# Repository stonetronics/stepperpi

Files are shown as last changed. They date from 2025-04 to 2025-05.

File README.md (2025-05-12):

# stepperpi
control of one stepper motor (NEMA17) and measurement by rotary encoder with a raspberry pi through a ethernet interface  

## pcb
The pcb folder contains a PCB that fits on to a regular raspberry pi (drawn in KiCAD 9.0). It holds two A4988 stepper motor drivers complete with JST connector for a NEMA17 motor and two JST connectors for endswitches, all following common pin layouts as they are used with 3D printers. Options for microstepping are set through a solder jumper.  
Each hardware pin connection of both the stepper driver and endswitches is connected to the raspberry pi through a solder jumper and can be enabled/disabled as needed.  
An additional DC/DC converter is present on the board. It steps down the input voltage to the 5V needed by the raspberry pi, eliminating the need for a seperate USB power supply. The connection to the DC/DC converter is optional and can be enabled through a jumper.  

## code
In the code directory, three subdirectories exist. One holds a jupyter notebook for the analysis and development of the stepping algorithm and the other one holds a c++ project for the control of the stepper motor on the raspberry pi through a socket interface. Another directory holds a client written in python which connects to the raspberry pi's socket and enables the user to send and receive string commands and messages. Please refer to the respective readme for further info.

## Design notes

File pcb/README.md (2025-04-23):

# PCB external content

This pcb uses/adapts external library content:

## A4988 step motor driver
3D model:  
https://grabcad.com/library/driver-a4988-1

## Raspberry Pi
3D model:  
https://grabcad.com/library/raspberry-pi-4-model-b-1
Footprint:
https://github.com/devbisme/RPi_Hat_Template

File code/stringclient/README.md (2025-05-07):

# stringclient

To use this client script run it via command line with `python client.py PLACE.RASPBERRYPI.IP.HERE`. Optionally, you can also set the host raspberry pi IP inside the python script and run it without arguments.  
At the start of the script, it will connect to the host.  

In order to send a string to the host, simply enter your string and press enter. If there is any response from the host, it will be displayed in the output of the script.  

Exit the script by entering the message `bye`.

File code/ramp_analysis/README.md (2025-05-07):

# ramp analysis

When a stepper motor is driven at constant speed directly from standstill, it faces very high torques and inertia which may lead to the loss of steps.  
In order to circumvent step loss when driving the stepper motor, an algorithm is employed which ramps up the speed with constant acceleration, holds the maximum speed and ramps down the speed again before reaching the desired number of steps. An exemplary resulting velocity profile is shown in the graph:  
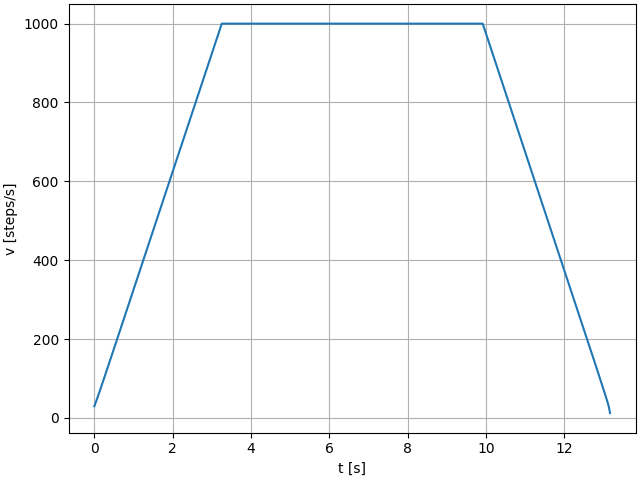
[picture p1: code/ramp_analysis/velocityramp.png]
velocityramp
  
  
The calculations in the python notebook serve as the basis for the development of the c++ code which runs on the raspberry pi and controls the stepper motor driver. In essence, the time between each step is the crucial quantity that is required to follow the velocity profile.

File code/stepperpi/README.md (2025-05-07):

# stepperpi c++ code  
This directory holds all of the c++ code that handles driving the stepper motor and exposing an interface on TCP which allows remote control of the system

## functional description  
TBW  

## requirements & install  
TBW  

## remote interface  
TBCD&TBW

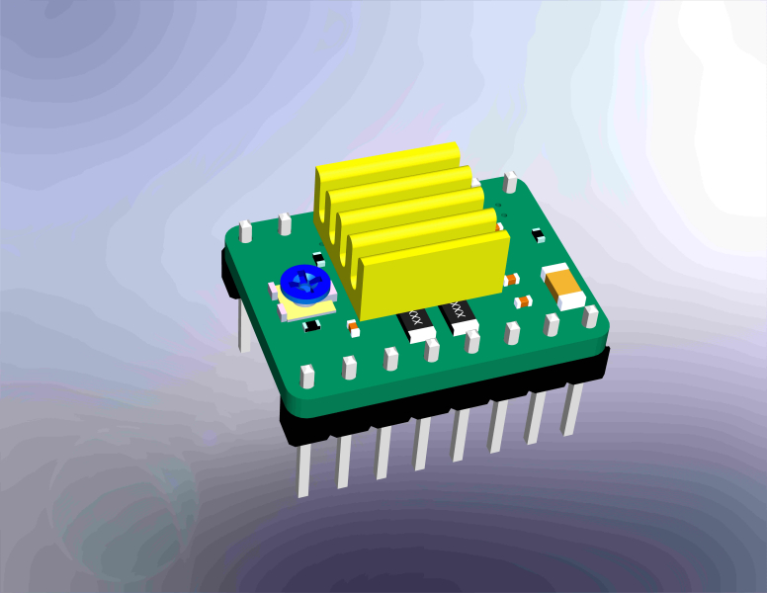
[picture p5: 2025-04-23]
pcb/stepperpi/3D/A4988/stepstick_1.jpg

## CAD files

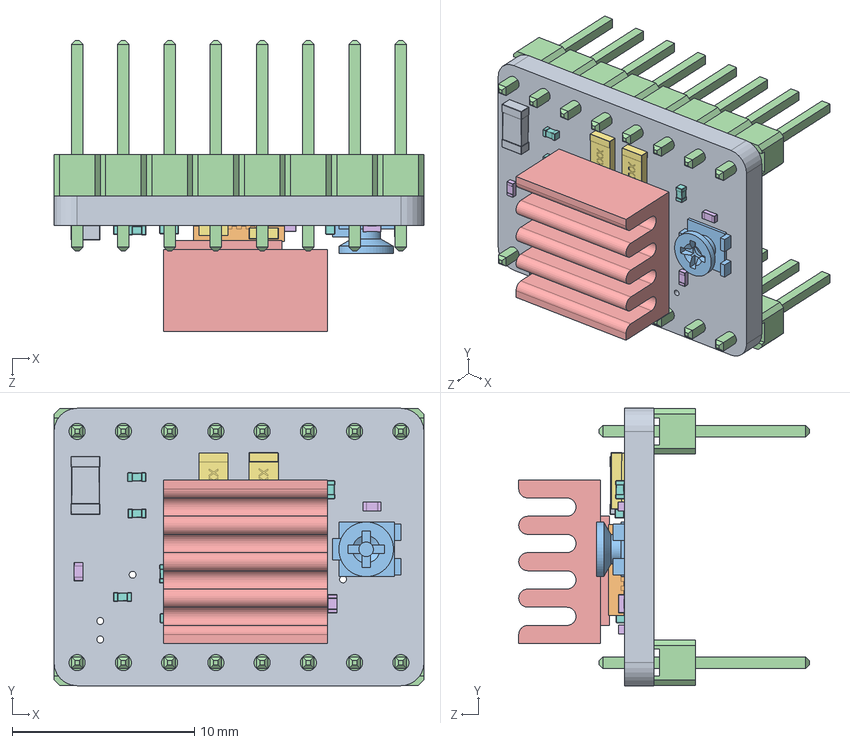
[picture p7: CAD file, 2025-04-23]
pcb/stepperpi/3D/A4988/stepstick.SLDASM
20.3 x 15.2 x 16.0 mm
stepstick
QFN28ET_A4983
TRIMPOT3MM_TRIMPOTSMD
Pin header pitch 2.54mm_08 contacts x 2
Heatsink For A4988
R0402-01 x 4
R1206-01 x 2
C0402 x 6
C1206B

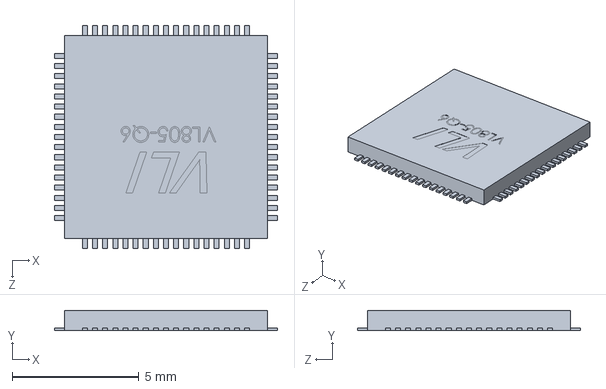
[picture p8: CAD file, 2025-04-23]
pcb/stepperpi/3D/raspberry/VIA VL805 PCIe USB 3.0 controller, RPi4ModelB.SLDPRT
8.80 x 0.8 x 8.80 mm

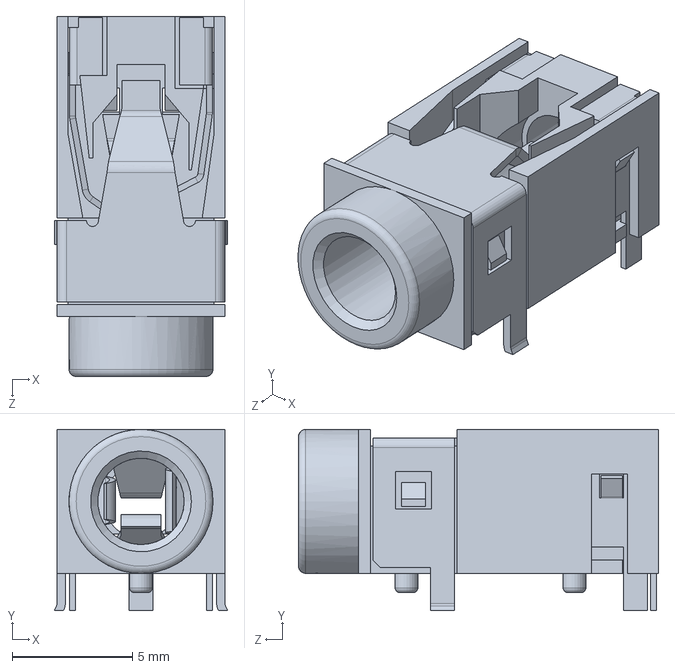
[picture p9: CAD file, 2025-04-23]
pcb/stepperpi/3D/raspberry/Microphone Plug, RPi4ModelB.SLDPRT
7.23 x 7.55 x 15.0 mm

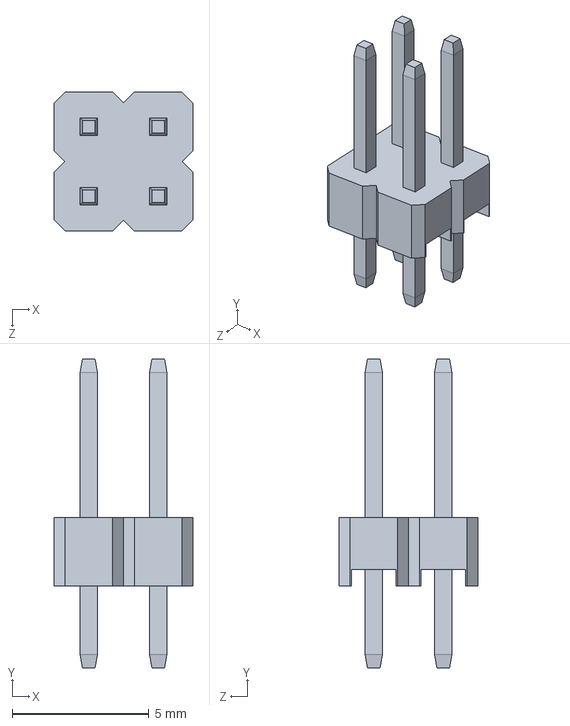
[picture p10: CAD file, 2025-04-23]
pcb/stepperpi/3D/raspberry/2.54 mm DUPONT MALE PIN HEADER, POE, 2X2, RPi4ModelB.SLDPRT
5.08 x 11.3 x 5.08 mm

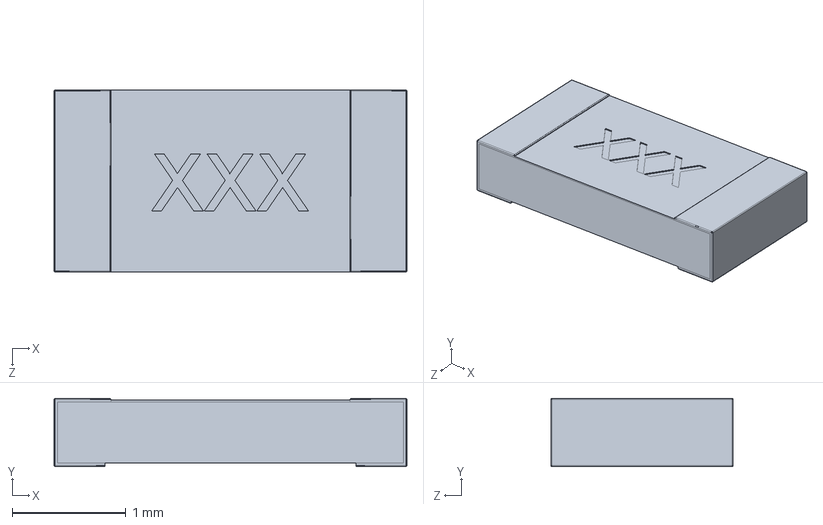
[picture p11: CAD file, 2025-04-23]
pcb/stepperpi/3D/A4988/R1206-01.SLDPRT
3.10 x 0.6 x 1.60 mm

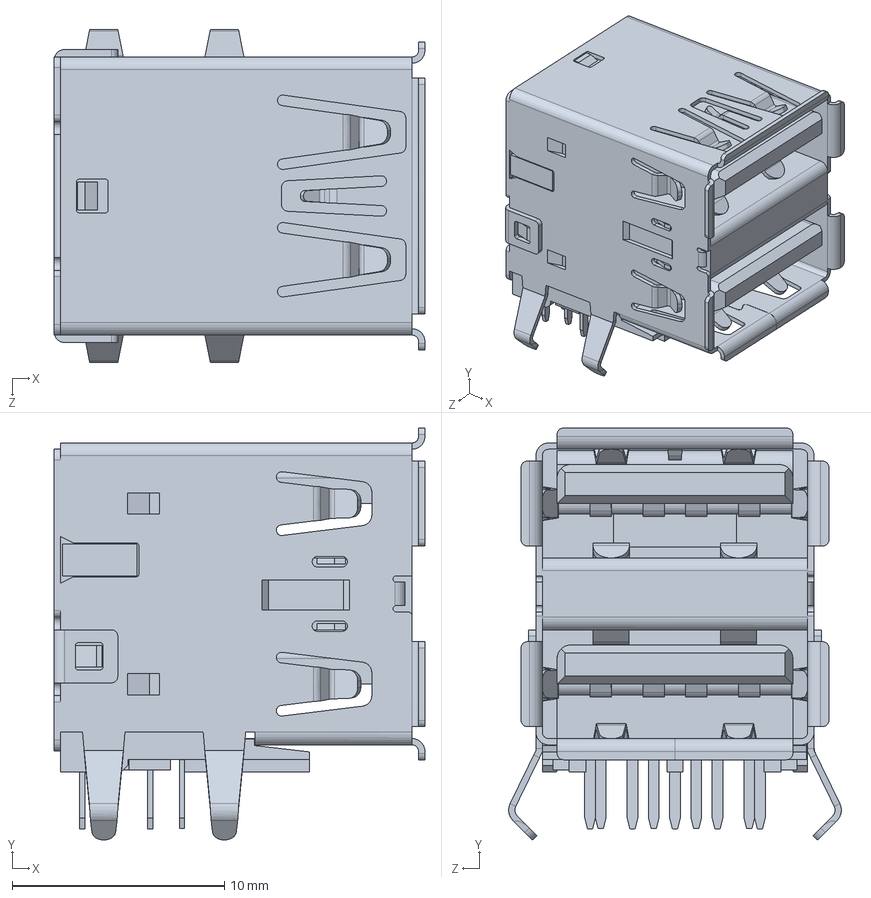
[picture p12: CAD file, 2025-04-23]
pcb/stepperpi/3D/raspberry/2X USB3.0 PORTS, RPi4ModelB.SLDPRT
17.5 x 19.4 x 15.7 mm

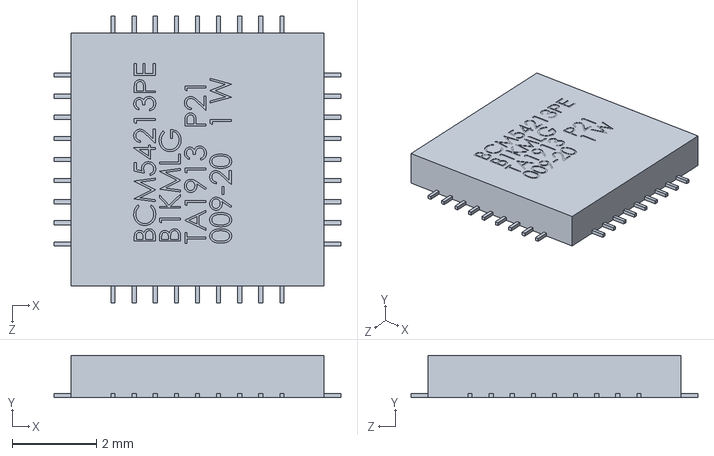
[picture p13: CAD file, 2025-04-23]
pcb/stepperpi/3D/raspberry/Broadcom BCM54213PE Gigabit Ethernet Transceiver, RPi4ModelB.SLDPRT
6.80 x 1.00 x 6.80 mm

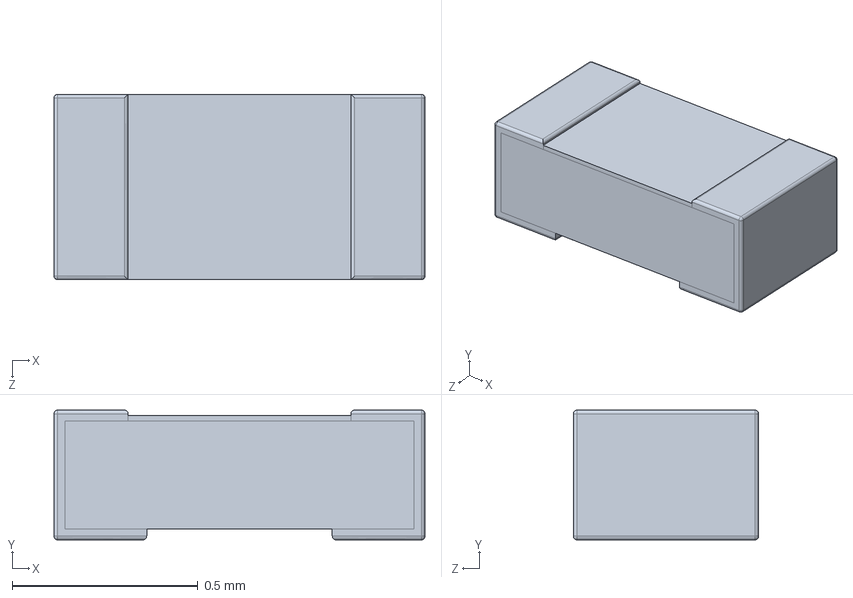
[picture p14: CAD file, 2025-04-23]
pcb/stepperpi/3D/A4988/R0402-01.SLDPRT
1.00 x 0.35 x 0.5 mm

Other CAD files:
pcb/stepperpi/3D/A4988/TRIMPOT3MM_TRIMPOTSMD.sldprt
pcb/stepperpi/3D/A4988/Pin header pitch 2.54mm_08 contacts.sldprt
pcb/stepperpi/3D/A4988/A4988-1.STEP
pcb/stepperpi/3D/A4988/0402RES_RESISTOR0402RES.sldprt
pcb/stepperpi/3D/A4988/Heatsink For A4988.sldprt
pcb/stepperpi/3D/A4988/QFN28ET_A4983.sldprt
pcb/stepperpi/3D/A4988/0805_RESISTOR.sldprt
pcb/stepperpi/3D/A4988/0402CAP_CAP0402CAP.sldprt
pcb/stepperpi/3D/A4988/1206_CAP1206.sldprt
pcb/stepperpi/3D/A4988/A4988-1.SLDASM
pcb/stepperpi/3D/A4988/C0402.SLDPRT
pcb/stepperpi/3D/A4988/C1206B.SLDPRT
pcb/stepperpi/3D/A4988/stepstick.sldprt
pcb/stepperpi/3D/raspberry/2.54 mm DUPONT MALE PIN HEADER, IO, 2X40, RPi4ModelB.SLDPRT
pcb/stepperpi/3D/raspberry/2X USB2.0 PORTS, RPi4ModelB.SLDPRT
pcb/stepperpi/3D/raspberry/Broadcom BCM2711B0 CPU, RPi4ModelB.SLDPRT
pcb/stepperpi/3D/raspberry/Cypress CYW43455 Wireless Module Cover, RPi4ModelB.SLDPRT
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

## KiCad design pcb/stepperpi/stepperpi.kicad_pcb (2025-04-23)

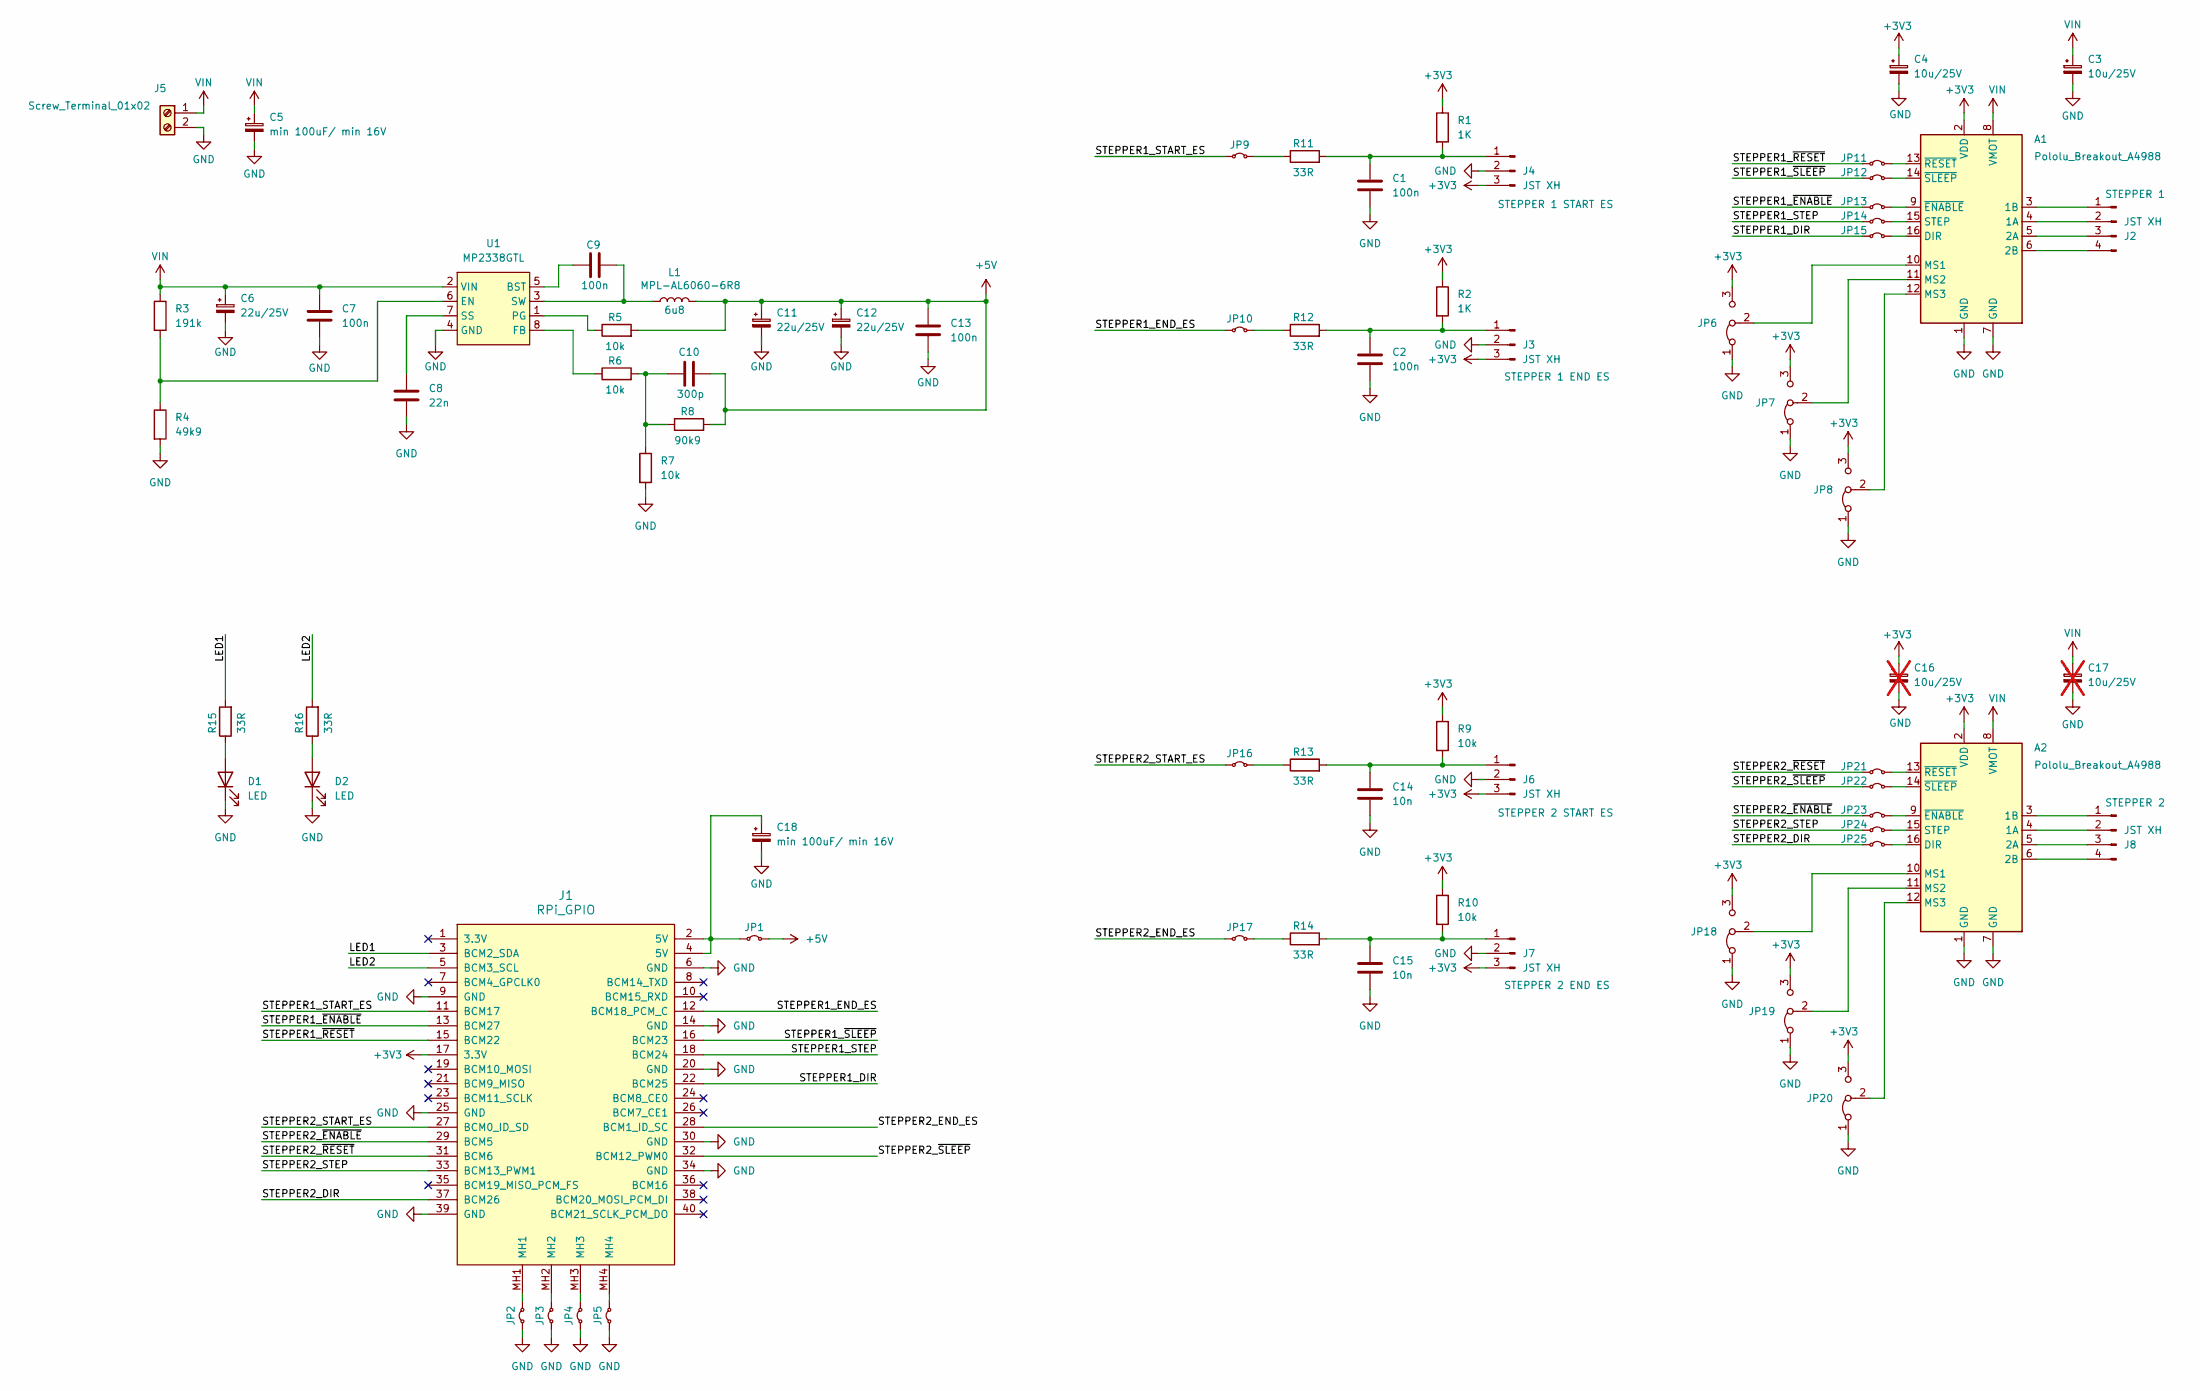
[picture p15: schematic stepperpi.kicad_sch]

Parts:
A1, A2: Pololu_Breakout_A4988; Pololu_Breakout-16_15.2x20.3mm
C1, C2, C7, C9, C13: 100n; C_0805_2012Metric
C3, C4: 10u/25V; CP_EIA-6032-28_Kemet-C_Pad2.25x2.35mm_HandSolder
C5, C18: min 100uF/ min 16V; CP_EIA-7343-31_Kemet-D_Pad2.25x2.55mm_HandSolder
C6, C11, C12: 22u/25V; CP_EIA-7132-28_AVX-C_Pad2.72x3.50mm_HandSolder
C8: 22n; C_0805_2012Metric
C10: 300p; C_0805_2012Metric
C14, C15: 10n; C_0805_2012Metric
C16, C17: 10u/25V; CP_EIA-6032-28_Kemet-C_Pad2.25x2.35mm_HandSolder; not fitted
D1, D2: LED; LED_0805_2012Metric_Pad1.15x1.40mm_HandSolder
J1: RPi_GPIO; RPI_Hat_B+ no display slot
J2, J8: JST XH; JST_XH_B4B-XH-A_1x04_P2.50mm_Vertical
J3, J4, J6, J7: JST XH; JST_XH_B3B-XH-A_1x03_P2.50mm_Vertical
J5: Screw_Terminal_01x02; TerminalBlock_bornier-2_P5.08mm
JP1, JP2, JP3, JP4, JP5, JP9, JP10, JP11, JP12, JP13, JP14, JP15, JP16, JP17, JP21, JP22, JP23, JP24, JP25: Jumper_2_Small_Bridged; SolderJumper-2_P1.3mm_Open_TrianglePad1.0x1.5mm
JP6, JP7, JP8, JP18, JP19, JP20: Jumper_3_Bridged12; SolderJumper-3_P2.0mm_Open_TrianglePad1.0x1.5mm_NumberLabels
L1: 6u8; L_MPL-AL6060-6R8; Part MPL-AL6060-6R8
R1, R2: 1K; R_0805_2012Metric
R3: 191k; R_0805_2012Metric
R4: 49k9; R_0805_2012Metric
R5, R6, R7, R9, R10: 10k; R_0805_2012Metric
R8: 90k9; R_0805_2012Metric
R11, R12, R13, R14, R15, R16: 33R; R_0805_2012Metric
U1: MP2338GTL; SOT-583-8

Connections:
+3V3: A1.2 (VDD), A2.2 (VDD), C4.1, C16.1, J1.17 (3.3V), J3.3, J4.3, J6.3, J7.3, JP6.3 (B), JP7.3 (B), JP8.3 (B), JP18.3 (B), JP19.3 (B), JP20.3 (B), R1.1, R2.1, R9.1, R10.1
+5V: C10.2, C11.1, C12.1, C13.1, JP1.1 (A), L1.2, R5.2, R8.2
/LED1: J1.3 (BCM2_SDA), R15.2
/LED2: J1.5 (BCM3_SCL), R16.2
/STEPPER1_DIR: J1.22 (BCM25), JP15.1 (A)
/STEPPER1_END_ES: J1.12 (BCM18_PCM_C), JP10.1 (A)
/STEPPER1_START_ES: J1.11 (BCM17), JP9.1 (A)
/STEPPER1_STEP: J1.18 (BCM24), JP14.1 (A)
/STEPPER1_~ENABLE: J1.13 (BCM27), JP13.1 (A)
/STEPPER1_~RESET: J1.15 (BCM22), JP11.1 (A)
/STEPPER1_~SLEEP: J1.16 (BCM23), JP12.1 (A)
/STEPPER2_DIR: J1.37 (BCM26), JP25.1 (A)
/STEPPER2_END_ES: J1.28 (BCM1_ID_SC), JP17.1 (A)
/STEPPER2_START_ES: J1.27 (BCM0_ID_SD), JP16.1 (A)
/STEPPER2_STEP: J1.33 (BCM13_PWM1), JP24.1 (A)
/STEPPER2_~ENABLE: J1.29 (BCM5), JP23.1 (A)
/STEPPER2_~RESET: J1.31 (BCM6), JP21.1 (A)
/STEPPER2_~SLEEP: J1.32 (BCM12_PWM0), JP22.1 (A)
GND: A1.1 (GND), A1.7 (GND), A2.1 (GND), A2.7 (GND), C1.2, C2.2, C3.2, C4.2, C5.2, C6.2, C7.2, C8.2, C11.2, C12.2, C13.2, C14.2, C15.2, C16.2, C17.2, C18.2, D1.1 (K), D2.1 (K), J1.6 (GND), J1.9 (GND), J1.14 (GND), J1.20 (GND), J1.25 (GND), J1.30 (GND), J1.34 (GND), J1.39 (GND), J3.2, J4.2, J5.2, J6.2, J7.2, JP2.1 (A), JP3.1 (A), JP4.1 (A), JP5.1 (A), JP6.1 (A), JP7.1 (A), JP8.1 (A), JP18.1 (A), JP19.1 (A), JP20.1 (A), R4.2, R7.2, U1.4 (GND)
unnamed: A1.4 (1A), J2.2
unnamed: A1.3 (1B), J2.1
unnamed: A1.5 (2A), J2.3
unnamed: A1.6 (2B), J2.4
unnamed: A1.16 (DIR), JP15.2 (B)
unnamed: A1.10 (MS1), JP6.2 (C)
unnamed: A1.11 (MS2), JP7.2 (C)
unnamed: A1.12 (MS3), JP8.2 (C)
unnamed: A1.15 (STEP), JP14.2 (B)
unnamed: A1.9 (~ENABLE), JP13.2 (B)
unnamed: A1.13 (~RESET), JP11.2 (B)
unnamed: A1.14 (~SLEEP), JP12.2 (B)
unnamed: A2.4 (1A), J8.2
unnamed: A2.3 (1B), J8.1
unnamed: A2.5 (2A), J8.3
unnamed: A2.6 (2B), J8.4
unnamed: A2.16 (DIR), JP25.2 (B)
unnamed: A2.10 (MS1), JP18.2 (C)
unnamed: A2.11 (MS2), JP19.2 (C)
unnamed: A2.12 (MS3), JP20.2 (C)
unnamed: A2.15 (STEP), JP24.2 (B)
unnamed: A2.9 (~ENABLE), JP23.2 (B)
unnamed: A2.13 (~RESET), JP21.2 (B)
unnamed: A2.14 (~SLEEP), JP22.2 (B)
unnamed: C10.1, R6.2, R7.1, R8.1
unnamed: D1.2 (A), R15.1
unnamed: D2.2 (A), R16.1
unnamed: C2.1, J3.1, R2.2, R12.2
unnamed: C1.1, J4.1, R1.2, R11.2
unnamed: C14.1, J6.1, R9.2, R13.2
unnamed: C15.1, J7.1, R10.2, R14.2
unnamed: C18.1, J1.2 (5V), J1.4 (5V), JP1.2 (B)
unnamed: J1.MH1, JP2.2 (B)
unnamed: J1.MH2, JP3.2 (B)
unnamed: J1.MH3, JP4.2 (B)
unnamed: J1.MH4, JP5.2 (B)
unnamed: JP9.2 (B), R11.1
unnamed: JP10.2 (B), R12.1
unnamed: JP16.2 (B), R13.1
unnamed: JP17.2 (B), R14.1
unnamed: C9.1, U1.5 (BST)
unnamed: R3.2, R4.1, U1.6 (EN)
unnamed: R6.1, U1.8 (FB)
unnamed: R5.1, U1.1 (PG)
unnamed: C8.1, U1.7 (SS)
unnamed: C9.2, L1.1, U1.3 (SW)
VIN: A1.8 (VMOT), A2.8 (VMOT), C3.1, C5.1, C6.1, C7.1, C17.1, J5.1, R3.1, U1.2 (VIN)

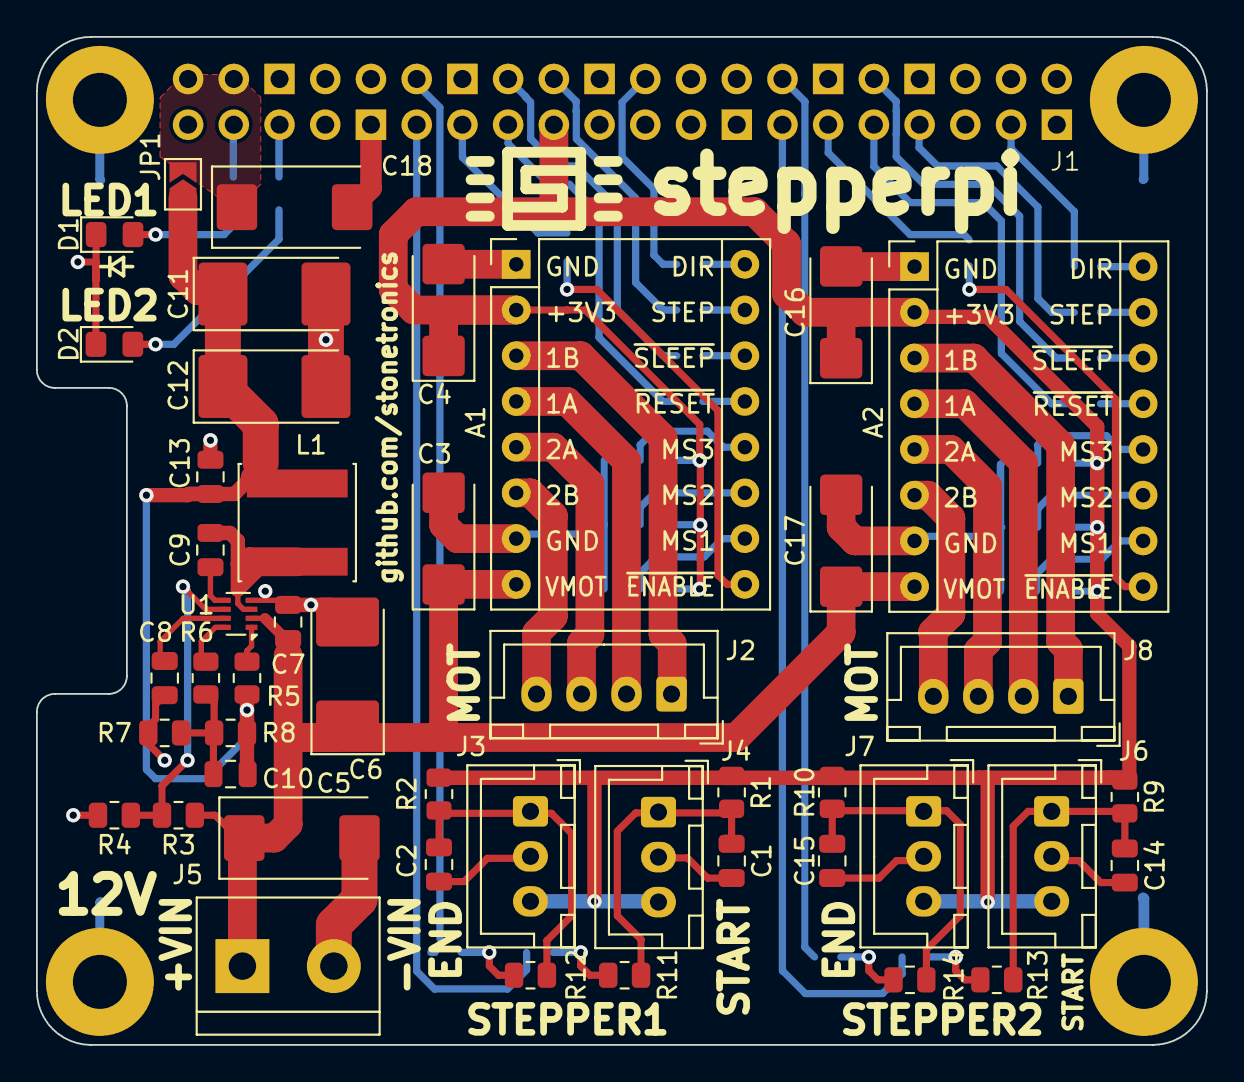
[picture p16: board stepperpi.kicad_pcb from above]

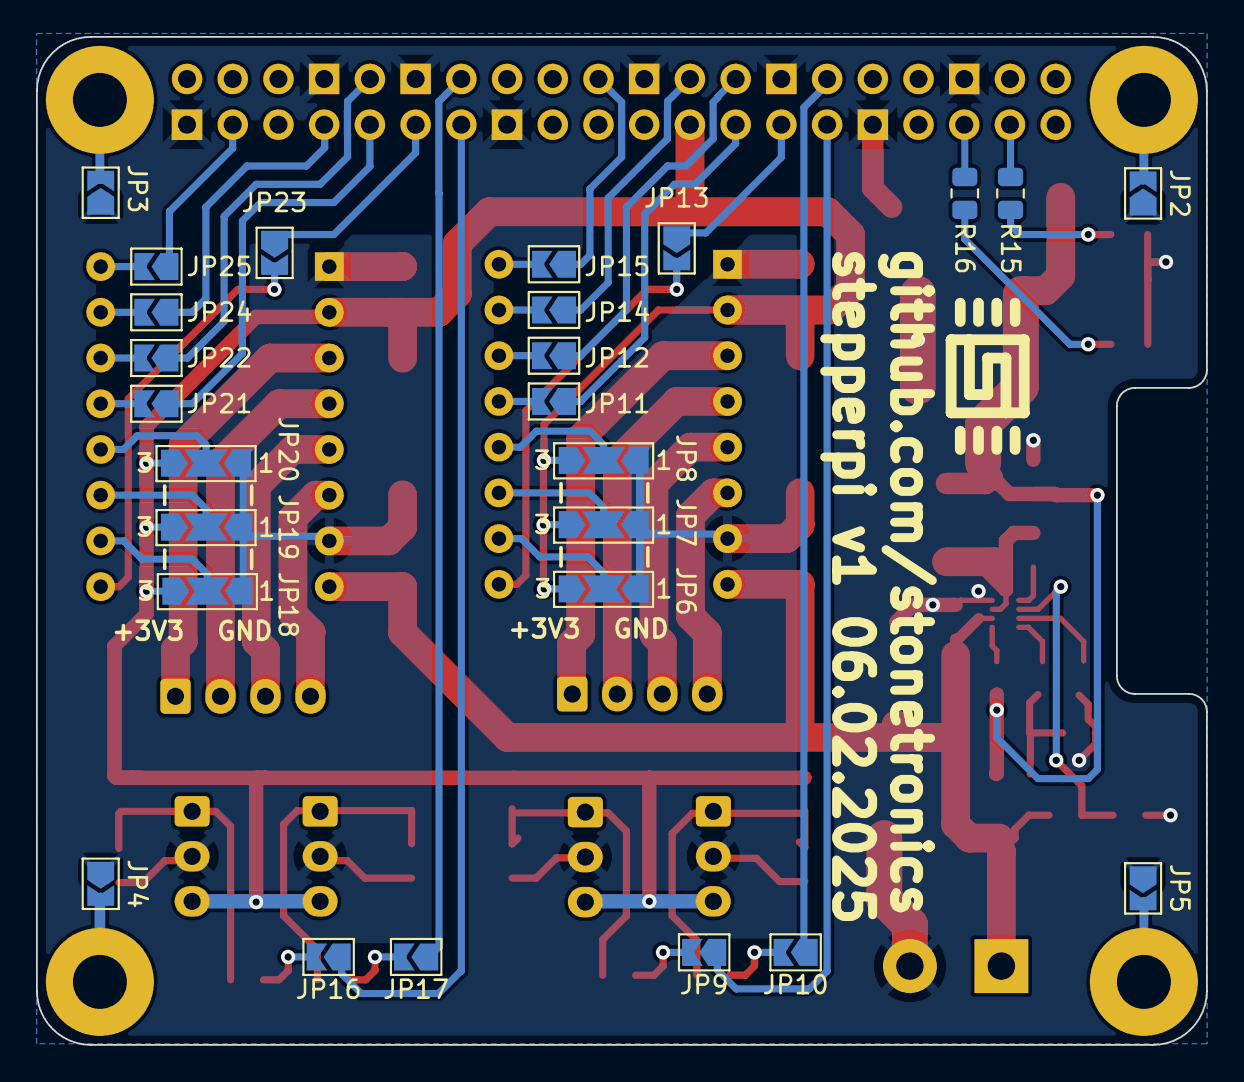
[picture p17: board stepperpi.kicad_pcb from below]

Board: 2 copper layers, 65.0 x 56.0 mm, 73 parts (26 on the bottom side), 66 nets.

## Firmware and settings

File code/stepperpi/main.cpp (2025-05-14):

/*

Multi-threaded application that receives commands for a stepper motor on a socket and executes the desired stepper steps rotation woohoo

build command: g++ *.cpp -o main -lpthread -lbcm2835


*/


#include <cstring>
#include <iostream>
using namespace std;
#include <netinet/in.h>
#include <sys/socket.h>
#include <unistd.h>
#include <signal.h>
#include <pthread.h>
#include <cmath>
#include "CircBuffer.h"

/*
uses the bcm2835 library as found on https://www.airspayce.com/mikem/bcm2835/index.html, version 1.75 at the time of coding this
download and install beforehand
*/
#include <bcm2835.h>
#include "stepper.h"
#include "encoder.h"
#include "parser.h"

#include "pindef.h"


#define COMMAND_BUFFER_SIZE     128 //number of commmands that can be stored at once

#define TRANSMIT_MSG_SIZE       256 //transmit message maximum string length
#define TRANSMIT_BUFFER_SIZE    128 // number of transmit messages that can be stored at once

#define SERVER_PORT     8000

typedef enum {
    RIGHT = 0, LEFT = 1
} Direction;

/*
GENERAL APPLICATION RUN & EXIT HANDLING
*/
volatile int running;

void my_handler(int s){
    cout << "Caught signal " << s << endl;
    cout << "stopping program..." << endl;
    // signal the stop to all threads
    running = 0;
}

// type that stores transmission strings
typedef struct {
    char msg[TRANSMIT_MSG_SIZE];
} Transmit_Msg;

/* all server info */
typedef struct {
    pthread_t   receive_thread_id;                  // receiver thread id
    pthread_t   transmit_thread_id;                 // transmission thread id
    pthread_t   stepper_thread_id;                  // stepper handling thread id
    pthread_t   encoder_thread_id;                  // encoder thread id
    pthread_t   manual_thread_id;                   // manual control thread id
    int server_port;                                // port to listen on
    int server_socket;                              // file descriptor of server socket
    int client_socket;                              // file descriptor of the client socket
    CircBuffer<Transmit_Msg>* transmit_buffer;      // buffer where transmissions are saved
    CircBuffer<Stepper_Command>* command_buffer;    // stepper command buffer
    Stepper* stepper;                               // the stepper
    Encoder* encoder;                               // the encoder
    pthread_mutex_t client_lock;                    // lock for the client server
} Server_Info;

/*socket open indicator*/
volatile int socket_open;

/*void* debug_transmitter(void* param) {
    Server_Info* si = (Server_Info*) param;
    Transmit_Msg msg;
    int counter = 0;

    while (running && socket_open) {
        sleep(3); //send something every three minutes
        sprintf(msg.msg, "Debug message number %d", counter++);
        si->transmit_buffer->write(msg);
    }

    return (void*) "Happy Debugging";
}*/

/*transmit handling*/
void* transmit_thread(void* param) {
    Server_Info* si = (Server_Info*) param;

    Transmit_Msg msg;

    cout << "[transmit] transmission thread started!" << endl;

    while (socket_open && running) {
        if (!(si->transmit_buffer->empty()) ){
            msg = si->transmit_buffer->read();
            cout << "[transmit] message in buffer: " << msg.msg << endl;
            cout << "[transmit] sending ... " << endl;
            //pthread_mutex_lock(&(si->client_lock));
            send(si->client_socket, msg.msg, strlen(msg.msg), 0);
            //pthread_mutex_unlock(&(si->client_lock));
        }
    }

    cout << "[transmit] ending transmission thread!" << endl;

    return (void* ) "no error";

}

/*Receive handling*/
void* receive_thread(void* param) {
    Server_Info* si = (Server_Info*) param; // get server infos

    char buffer[1024]; // receive buffer
    int msglen;        // length of received message

    cout << "[receive] started receive thread" << endl;

    while (socket_open && running) {
        cout << "[receive] try to receive" << endl;
        //pthread_mutex_lock(&(si->client_lock));
        msglen = recv(si->client_socket, buffer, sizeof(buffer), 0);
        //pthread_mutex_unlock(&(si->client_lock));
        if (msglen>0) {
            cout << "[receive] Message from client: ";
            buffer[msglen] = '\0';
            for(int i =0; i < msglen; i++) {
                cout << buffer[i];
            }
            cout << endl;
            /*do something with the message*/
            Stepper_Command tmp_command;
            if ( !parse_stepper_command(buffer, &tmp_command) ) {
                cout << "[receive] found command: ";
                print_stepper_command(tmp_command);
                cout << endl;
                cout << "[receive] feeding queue: ";
                if ( si->command_buffer->write(tmp_command) ) {
                    cout << "[receive] OK" << endl;
                } else {
                    cout << "[receive] buffer not empty!" << endl;
                }
            } else {
                cout << "[receive] could not process command!" << endl;
            }

            /*
            Transmit_Msg msg;
            strcpy(msg.msg, buffer);
            si->transmit_buffer->write(msg);*/
        } else {
            cout << "[receive] msglen read: " << msglen << endl;
            if (msglen == 0) {
                cout << "[receive] Client disconnected! stopping thread" << endl;
                socket_open = 0;
            }
        }
    }

    cout << "[receive] end of receive thread" << endl;

    return (void*) "no error";
}

/*seperate thread for encoder*/
void* encoder_thread(void* param) {
    Server_Info* si = (Server_Info*) param; // get server infos
    cout << "[encoderthread] encoder thread started!" << endl;
    while (running) {
        si->encoder->process();
    }

    return NULL;
}

/*Handle single stepper commands*/
void* stepper_thread(void* param) {
    Server_Info* si = (Server_Info*) param; // get server infos

    cout << "[stepperthread] stepper thread started!" << endl;

    int toggle_interval_millis;

    int rotation_count_before;
    int illegal_count_before;
    int rotation_count_after;   //to store encoder counts before and after movement - to check wether the motor moves for real
    int illegal_count_after;   

    int stepper_retval;
    Transmit_Msg msg;  //message to return

    while (running) {
        if (!si->command_buffer->empty()) {
            cout << "[stepperthread] new command in queue. processing ..." << endl;
            Stepper_Command tmp_command = si->command_buffer->read();
            switch (tmp_command.type) {
                case RESET:
                    cout << "[stepperthread] resetting hardware" << endl;
                    strcpy(msg.msg, "resetting hardware");
                    si->transmit_buffer->write(msg);
                    si->stepper->reset();
                    break;

                case ENABLE:
                    cout << "[stepperthread] enabling hardware" << endl;
                    strcpy(msg.msg, "enabling hardware");
                    si->transmit_buffer->write(msg);
                    si->stepper->enable(true);
                    si->stepper->sleep(false);
                    break;
                    
                case DISABLE:
                    cout << "[stepperthread] disabling hardware" << endl;
                    strcpy(msg.msg, "disabling hardware");
                    si->transmit_buffer->write(msg);
                    si->stepper->enable(false);
                    si->stepper->sleep(true);
                    break;

                case MOVE:
                    cout << "[stepperthread] stepping " << tmp_command.steps << " steps in direction " << tmp_command.direction << endl;
                    cout << "[stepperthread] endswitches are obeyed!" << endl;

                    // get encoder values before
                    rotation_count_before = si->encoder->getRotationCount();
                    illegal_count_before = si->encoder->getIllegalCount();

                    //do the stepping
                    if (tmp_command.acceleration <= 0) {
                        sprintf(msg.msg, "stepping %d steps in direction %d, requested speed: %.2f steps/s; default acceleration; endswitches are obeyed!", tmp_command.steps, tmp_command.direction, tmp_command.speed);
                        si->transmit_buffer->write(msg);
                        stepper_retval = si->stepper->step(tmp_command.direction, tmp_command.steps, tmp_command.speed);
                    } else {
                        sprintf(msg.msg, "stepping %d steps in direction %d, requested speed: %.2f steps/s; acceleration: %.2f steps/s/s; endswitches are obeyed!", tmp_command.steps, tmp_command.direction, tmp_command.speed, tmp_command.acceleration);
                        si->transmit_buffer->write(msg);
                        stepper_retval = si->stepper->step(tmp_command.direction, tmp_command.steps, tmp_command.speed, tmp_command.acceleration);
                    }
                    //report

                    // get encoder values after
                    rotation_count_after = si->encoder->getRotationCount();
                    illegal_count_after = si->encoder->getIllegalCount();

                    cout << "[stepperthread] rotation count: " << rotation_count_after << "; illegal count: " << illegal_count_after << ";" << endl;
                    if ( (rotation_count_after == rotation_count_before) && (illegal_count_after == illegal_count_before) ) {
                        cout << "[stepperthread] encoder did not recognize any movement! check motor/encoder - maybe hardware is not enabled?" << endl;
                        sprintf(msg.msg, "Warning: encoder did not recognize any movement! rotation count: %d; illegal count: %d", rotation_count_after, illegal_count_after);
                        si->transmit_buffer->write(msg);
                    } else {
                        sprintf(msg.msg, "Encoder recognized movement! rotation count: %d; illegal count: %d", rotation_count_after, illegal_count_after);
                        si->transmit_buffer->write(msg);
                    }


                    if (!stepper_retval) {
                        cout << "[stepperthread] stepping finished without endstops hitting!" << endl;
                        strcpy(msg.msg, "stepping finished without endstops hitting!");
                        si->transmit_buffer->write(msg);
                    } else {
                        cout << "[stepperthread] stepped into one of the endstops!" << endl;
                        strcpy(msg.msg, "stepped into one of the endstops!");
                        si->transmit_buffer->write(msg);
                        
                    }
                    break;

                case HARDMOVE:
                    if (tmp_command.acceleration <= 0) {
                        cout << "[stepperthread] cannot hardstep, missing acceleration!" << endl;
                        strcpy(msg.msg, "cannot hardstep, missing acceleration!");
                        si->transmit_buffer->write(msg);
                    } else {
                        cout << "[stepperthread] stepping " << tmp_command.steps << " steps in direction" << tmp_command.direction << endl;
                        cout << "[stepperthread] endswitches are !!!NOT!!! obeyed!" << endl;
                        sprintf(msg.msg, "stepping %d steps in direction %d, requested speed: %.2f steps/s; acceleration: %.2f steps/s/s; endswitches are !!!NOT!!! obeyed!", tmp_command.steps, tmp_command.direction, tmp_command.speed, tmp_command.acceleration);
                        si->transmit_buffer->write(msg);
                        si->stepper->step(tmp_command.direction, tmp_command.steps, tmp_command.speed, tmp_command.acceleration, false);
                        cout << "[stepperthread] finished stepping!" << endl;
                        strcpy(msg.msg, "finished stepping!");
                        si->transmit_buffer->write(msg);
                    }
                    break;

                case ENCODER_RESET:
                    si->encoder->resetCounters();
                    cout << "[stepperthread] reset encoder values!" << endl;
                    strcpy(msg.msg,  "reset encoder values!");
                    si->transmit_buffer->write(msg);
                    break;
                    
                case ENCODER_GET:
                    rotation_count_before = si->encoder->getRotationCount(); //reuse variables, the "_before" doesnt mean anything here
                    illegal_count_before = si->encoder->getIllegalCount();
                    cout << "[stepperthread] got rotation count: " << rotation_count_before << "; and illegal count: " << illegal_count_before << ";" << endl;

                    sprintf(msg.msg, "rotation count:%d; illegal count:%d;", rotation_count_before, illegal_count_before);
                    si->transmit_buffer->write(msg);
                    break;

                case DEBUG:
                    stepper_retval = si->stepper->debug();

                    sprintf(msg.msg, "DEBUG; DIR:%d, STEP:%d, nSLEEP:%d, nRESET:%d, nENABLE:%d, START_ENDSTOP:%d, END_ENDSTOP:%d, rotation count:%d, illegal count:%d", (stepper_retval&(1<<6))>>6, (stepper_retval&(1<<5))>>5, (stepper_retval&(1<<4))>>4, (stepper_retval&(1<<3))>>3, (stepper_retval&(1<<2))>>2,(stepper_retval&(1<<1))>>1, (stepper_retval&(1<<0))>>0, si->encoder->getRotationCount(), si->encoder->getIllegalCount());
                    si->transmit_buffer->write(msg);
                    break;

                default:
                    cout << "[stepperthread] can not process command! going to next command" << endl;
                    break;
            }
            if (si->command_buffer->empty() ) {
                cout << "[stepperthread] no commands left!" << endl;
            }
        }
    }

    cout << "[stepperthread] stepper thread ended!" << endl;

    return NULL;
}
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
int main()
{
    running = 1;

    // strg+c handling
    struct sigaction sigIntHandler;
    sigIntHandler.sa_handler = my_handler;
    sigemptyset(&sigIntHandler.sa_mask);
    sigIntHandler.sa_flags = 0;
    sigaction(SIGINT, &sigIntHandler, NULL);

    // set up socket
    Server_Info si;
    si.server_port = SERVER_PORT;
    setup_socket(&si);

    // setup transmission buffer
    CircBuffer<Transmit_Msg> transmit_buffer(TRANSMIT_BUFFER_SIZE);
    si.transmit_buffer = &transmit_buffer;
    
    // setup stepper command buffer
    CircBuffer<Stepper_Command> command_buffer(COMMAND_BUFFER_SIZE);
    si.command_buffer = &command_buffer;

    // setup stepper module
    Stepper stepper(A4988_DIR, A4988_STEP, A4988_nSLEEP, A4988_nRESET, A4988_nENABLE, ENDSTOP_START, ENDSTOP_STOP);

    // setup encoder module
    Encoder encoder(LIGHTBARRIER_A, LIGHTBARRIER_B);

    //init gpio lib
    if (!bcm2835_init()) {
        cout << "Unable to init GPIO." << endl;
        return 1;
    }

    //set configuration - to be hardwired
    //no microstepping
    #ifdef SET_MICROSTEPS_PINS
        bcm2835_gpio_fsel(A4988_MS1, BCM2835_GPIO_FSEL_OUTP);
        bcm2835_gpio_fsel(A4988_MS2, BCM2835_GPIO_FSEL_OUTP);
        bcm2835_gpio_fsel(A4988_MS3, BCM2835_GPIO_FSEL_OUTP);
        bcm2835_gpio_write(A4988_MS1, LOW);
        bcm2835_gpio_write(A4988_MS2, LOW);
        bcm2835_gpio_write(A4988_MS3, LOW);
    #endif

    // init led pins, keep them off at first
    bcm2835_gpio_fsel(LED1_PIN, BCM2835_GPIO_FSEL_OUTP);
    bcm2835_gpio_fsel(LED2_PIN, BCM2835_GPIO_FSEL_OUTP);
    bcm2835_gpio_write(LED1_PIN, LOW);
    bcm2835_gpio_write(LED2_PIN, LOW);
    
    // init manual control panel pins
    bcm2835_gpio_fsel(MANUAL_LED, BCM2835_GPIO_FSEL_OUTP);
    bcm2835_gpio_write(MANUAL_LED, LOW);
    bcm2835_gpio_fsel(MANUAL_ENABLE, BCM2835_GPIO_FSEL_INPT);
    bcm2835_gpio_fsel(MANUAL_LEFT, BCM2835_GPIO_FSEL_INPT);
    bcm2835_gpio_fsel(MANUAL_RIGHT, BCM2835_GPIO_FSEL_INPT);
    
    //init stepper
    stepper.init();
    si.stepper = &stepper; //save to server info
    
    //init encoder
    encoder.init();
    si.encoder = &encoder; //save to server info
    
    // set up mutex for threadsafety of the client server
    if (pthread_mutex_init(&(si.client_lock), NULL)!= 0) {
        cout << "[main] client server mutex initialization failed! " << endl;
    }

    // set up stepper thread
    pthread_create(&(si.stepper_thread_id), NULL, &stepper_thread, &si);

    // set up encoder thread
    pthread_create(&(si.encoder_thread_id), NULL, &encoder_thread, &si);
    
    // set up manual control thread
    pthread_create(&(si.manual_thread_id), NULL, &manual_thread, &si);

    //signal that the program is running and ready to accept manual commands
    bcm2835_gpio_write(MANUAL_LED, HIGH);
    
    cout << "[main] DEBUG: " << si.server_port << "; " << si.server_socket << endl;
    
    struct sockaddr_in client; // for recording the client infos
    unsigned int namelen;

    // return values for all threads
    void* receive_thread_return;
    void* transmit_thread_return;
    void* stepper_thread_return;
    void* encoder_thread_return;
    void* manual_thread_return;
    
    while (running) {
        cout << "[main] Accepting connection on port " << si.server_port << "  with FD " << si.server_socket << endl;
        //signal that the server accepts connections on LED1
        bcm2835_gpio_write(LED1_PIN, HIGH);
        
        // get the lenght of the client info
        namelen = sizeof(client);
        
        // accept connection (sleep until a connection is made)
        if ( (si.client_socket = accept(si.server_socket, (struct sockaddr*) &client, &namelen )) == -1 ){
            cout << "[main] error in accepting client connection: " << si.client_socket << endl;
            cout << "[main] exiting main loop!" << endl;
            break;
        } else {
            cout << "[main] accepted client connection" << endl;
            // signal that a connection was accepted on LED2
            bcm2835_gpio_write(LED2_PIN, HIGH);
        }
        
        socket_open = 1;
        //reset the transmit buffer before starting threads
        si.transmit_buffer->reset();
        //with the accepted connection, start the receiving and transmitting thread
        pthread_create(&(si.receive_thread_id), NULL, &receive_thread, &si);
        pthread_create(&(si.transmit_thread_id), NULL, &transmit_thread, &si);
        
        
        /* for debug
        pthread_t debug_thread_id;
        pthread_create(&debug_thread_id, NULL, &debug_transmitter, &si);
        void* debug_thread_return;
        pthread_join(debug_thread_id, &debug_thread_return);
        cout << "[main] debg thread stopped, exited with return: " << (char*) debug_thread_return << endl;*/
        
        // wait for transmission and reception thread to finish
        pthread_join(si.receive_thread_id, &receive_thread_return);
        cout << "[main] receiver thread stopped, exited with return: " << (char*) receive_thread_return << endl;
        pthread_join(si.transmit_thread_id, &transmit_thread_return);
        cout << "[main] transmission thread stopped, exited with return: " << (char*) transmit_thread_return << endl;
        
        //signal that no accepting is done right now and no connection is given on the socket
        bcm2835_gpio_write(LED1_PIN, LOW);
        bcm2835_gpio_write(LED2_PIN, LOW);
        
        
        sleep(1); // sleep 1 second before accepting connections again
    }

    //signal that the program is stopped
    bcm2835_gpio_write(MANUAL_LED, LOW);

    pthread_join(si.stepper_thread_id, &stepper_thread_return);
    pthread_join(si.encoder_thread_id, &encoder_thread_return);
    pthread_join(si.manual_thread_id, &manual_thread_return);
    
    close(si.client_socket);
    // shutdown socket
    shutdown(si.server_socket, SHUT_RDWR);
    close(si.server_socket);
    
    // release stepper control
    stepper.sleep(true);
    stepper.enable(false);

    //make sure no false indication is on the LEDs
    bcm2835_gpio_write(LED1_PIN, LOW);
    bcm2835_gpio_write(LED2_PIN, LOW);

    return 0;
}

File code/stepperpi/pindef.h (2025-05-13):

#define NO_STEPPERS             1

// GPIO connections from the schematic
#define STEPPER1_DIR        25
#define STEPPER1_STEP       24
#define STEPPER1_nSLEEP     23
#define STEPPER1_nRESET     22
#define STEPPER1_nENABLE    27
#define STEPPER1_START_ES   17
#define STEPPER1_END_ES     18

#define STEPPER2_DIR        26
#define STEPPER2_STEP       13
#define STEPPER2_nSLEEP     12
#define STEPPER2_nRESET     6
#define STEPPER2_nENABLE    5
#define STEPPER2_START_ES   0
#define STEPPER2_END_ES     1

//define GPIO connections which are used in the program
#define A4988_DIR       STEPPER1_DIR
#define A4988_STEP      STEPPER1_STEP
#define A4988_nSLEEP    STEPPER1_nSLEEP
#define A4988_nRESET    STEPPER1_nRESET
//#define SET_MICROSTEPS_PINS
#ifdef SET_MICROSTEPS_PINS
 #define A4988_MS3       11
 #define A4988_MS2       0
 #define A4988_MS1       5
#endif
#define A4988_nENABLE   STEPPER1_nENABLE
#define ENDSTOP_START   STEPPER1_START_ES
#define ENDSTOP_STOP    STEPPER1_END_ES


//set GPIO connections for LEDs
#define LED1_PIN    2
#define LED2_PIN    3


//set GPIO connections for rotary encoder
#define LIGHTBARRIER_A      STEPPER2_START_ES
#define LIGHTBARRIER_B      STEPPER2_END_ES


//set GPIO connections for manual mode panel
#define MANUAL_ENABLE   STEPPER2_STEP
#define MANUAL_LEFT     STEPPER2_nSLEEP
#define MANUAL_RIGHT    STEPPER2_nRESET
#define MANUAL_LED      STEPPER2_DIR

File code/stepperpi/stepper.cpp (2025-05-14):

#include "stepper.h"
#include <bcm2835.h>
#include <iostream>
#include <cmath>
using namespace std;

Stepper::Stepper( int pin_dir, int pin_step, int pin_nsleep, int pin_nreset, int pin_nenable, int pin_start_endstop, int pin_end_endstop) 
    : Stepper( pin_dir, pin_step, pin_nsleep, pin_nreset, pin_nenable, pin_start_endstop, pin_end_endstop, STEPPER_STANDARD_ACCELERATION){
}

Stepper::Stepper( int pin_dir, int pin_step, int pin_nsleep, int pin_nreset, int pin_nenable, int pin_start_endstop, int pin_end_endstop, float standard_acceleration) {
    this -> pin_dir = pin_dir;
    this -> pin_step = pin_step;
    this -> pin_nsleep = pin_nsleep;
    this -> pin_nreset = pin_nreset;
    this -> pin_nenable = pin_nenable;
    this -> pin_start_endstop = pin_start_endstop;
    this -> pin_end_endstop = pin_end_endstop;
    this -> standard_acceleration = standard_acceleration;

    if (pthread_mutex_init(&(this->lock), NULL)!= 0) 
    {
        cout << "[stepper]  mutex initialization failed! " << endl;
    }
}

void Stepper::init(void ) {
    //init IOs
    bcm2835_gpio_fsel(pin_dir, BCM2835_GPIO_FSEL_OUTP);
    bcm2835_gpio_fsel(pin_step, BCM2835_GPIO_FSEL_OUTP);
    bcm2835_gpio_fsel(pin_nsleep, BCM2835_GPIO_FSEL_OUTP);
    bcm2835_gpio_fsel(pin_nreset, BCM2835_GPIO_FSEL_OUTP);
    bcm2835_gpio_fsel(pin_nenable, BCM2835_GPIO_FSEL_OUTP);
    bcm2835_gpio_fsel(pin_start_endstop, BCM2835_GPIO_FSEL_INPT);
    bcm2835_gpio_fsel(pin_end_endstop, BCM2835_GPIO_FSEL_INPT); 

    //pull driver out of reset, dont sleep
    this->reset();
    this->sleep(false);
    //stepper_enable(true);


    cout << "[stepper] initialized!" << endl;
}

void Stepper::enable(bool enabled) {
    pthread_mutex_lock(&(this->lock));
    if (enabled) {
        //enable driver
        cout << "[stepper] enable" << endl;
        bcm2835_gpio_write(this->pin_nenable, LOW);
    } else {
        cout << "[stepper] disable" << endl;
        bcm2835_gpio_write(this->pin_nenable, HIGH);
    }
    pthread_mutex_unlock(&(this->lock));
}

bool Stepper::isEnabled( void ) {
    uint8_t enablepin = bcm2835_gpio_lev(this->pin_nenable);
    if (enablepin == LOW)
        return true;
    else
        return false;
}

int Stepper::step(int direction, int steps, float steprate) {
    return this->step(direction, steps, steprate, this->standard_acceleration, true);
}

int Stepper::step(int direction, int steps, float steprate, float acceleration) {
    return this->step(direction, steps, steprate, acceleration, true);
}

int Stepper::step(int direction, int steps, float steprate, float acceleration, bool obey_endstops) {
    int pin_endstop;
    int stepno = 0;

    pthread_mutex_lock(&(this->lock)); // lock mutex so nobody else can step

    if (direction) {
        cout << "[stepper] setting direction clockwise (end to start)" << endl;
        bcm2835_gpio_write(this->pin_dir, HIGH);
        pin_endstop = this->pin_start_endstop;
    } else {
        cout << "[stepper] setting direction counterclockwise (start to end)" << endl;
        bcm2835_gpio_write(this->pin_dir, LOW);
        pin_endstop = this->pin_end_endstop;
    }

    cout << "[stepper] stepping " << steps << " steps with " << steprate << " steps/s, acceleration at " << acceleration << " steps/s/s" << endl;
    cout << "[stepper] endstop switches are obeyed!" << endl;

    //calculate velocity ramps
    int no_ramp_steps = (int) (steprate*steprate /2.0/acceleration); //calculate how many steps the ramp runs
    if (steps < 2*no_ramp_steps) //handle case when full steprate cannot be reached
        no_ramp_steps = steps/2;

    //calculate the length of constant velocity
    int no_const_steps = steps - 2*no_ramp_steps;

    //   ramp up
    int i = 0;
    float step_duration_microseconds;
    while (i < no_ramp_steps) {
        //calculate step duration of the current step
        step_duration_microseconds = (sqrt(2.0*(i+1)/acceleration) - sqrt(2.0*(i)/acceleration)) * 1000000.0;
        if (obey_endstops && (bcm2835_gpio_lev(pin_endstop) == LOW)) //if the enddstop in the direction we want to rotate is pushed, stop stepping
            break;
        this->pulse_step_unsafe(step_duration_microseconds);
        i++;
        stepno++;
    }

    //   constant velocity
    step_duration_microseconds = 1000000.0/steprate;
    i=1;
    while (i++ < no_const_steps) {
        if (obey_endstops && (bcm2835_gpio_lev(pin_endstop) == LOW)) //if the enddstop in the direction we want to rotate is pushed, stop stepping
            break;
        this->pulse_step_unsafe(step_duration_microseconds);
        stepno++;
    }


    //   ramp down
    i = no_ramp_steps;
    while (i >= 0) {
        //calculate step duration of the current step
        step_duration_microseconds = (sqrt(2.0*(i+1)/acceleration) - sqrt(2.0*(i)/acceleration)) * 1000000.0;
        if (obey_endstops && (bcm2835_gpio_lev(pin_endstop) == LOW)) //if the enddstop in the direction we want to rotate is pushed, stop stepping
            break;
        this->pulse_step_unsafe(step_duration_microseconds);
        i--;
        stepno++;
    }

    //cout << "[DEBUG] stepno: " << stepno << endl;

    bcm2835_gpio_write(this->pin_step, LOW);
    
    pthread_mutex_unlock(&(this->lock));

    if (--stepno == steps) {
        cout << "[stepper] stepping finished without running into endstop!" << endl;
        return 0;
    } else {
        cout << "[stepper] stepping interrupted by running into endstop!" << endl;
        cout << "[stepper] stepped " << stepno << " of " << steps << " steps" << endl;  
        return 1;
    }

}

void Stepper::reset(void) {
    //enable driver
    pthread_mutex_lock(&(this->lock));
    cout << "[stepper] resetting stepper driver" << endl;
    bcm2835_gpio_write(this->pin_nreset, LOW);
    bcm2835_delay(10);
    bcm2835_gpio_write(this->pin_nreset, HIGH);
    pthread_mutex_unlock(&(this->lock));
}

void Stepper::sleep(bool sleep) {
    pthread_mutex_lock(&(this->lock));
    if (sleep) {
        cout << "[stepper] enter sleep" << endl;
        bcm2835_gpio_write(this->pin_nsleep, LOW);
    } else {
        cout << "[stepper] waking up" << endl;
        bcm2835_gpio_write(this->pin_nsleep, HIGH);
    }
    pthread_mutex_unlock(&(this->lock));
}

bool Stepper::isSleeping( void ) {
    uint8_t sleeppin = bcm2835_gpio_lev(this->pin_nsleep);
    if (sleeppin == LOW)
        return true;
    else
        return false;
}
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

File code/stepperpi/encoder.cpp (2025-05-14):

#include "encoder.h"
#include <bcm2835.h>
#include <iostream>
using namespace std;

//#define COUT_ON_GETTER

Encoder::Encoder( int pin_a, int pin_b)
    : Encoder(pin_a, pin_b, false) {
}

Encoder::Encoder(int pin_a, int pin_b, bool reverse_direction) {
    this->pin_a = pin_a;
    this->pin_b = pin_b;
    if (reverse_direction)
        this->directionMultiplier = -1;
    else
        this->directionMultiplier = 1;

    if (pthread_mutex_init(&(this->lock), NULL)!= 0) 
    {
        cout << "[encoder]  mutex initialization failed! " << endl;
    }
}

void Encoder::init( void ) {
    //init IOs
    bcm2835_gpio_fsel(this->pin_a, BCM2835_GPIO_FSEL_INPT);
    bcm2835_gpio_fsel(this->pin_b, BCM2835_GPIO_FSEL_INPT); 
    //read IOs for the first time
    this->pin_a_level_before = bcm2835_gpio_lev(this->pin_a);
    this->pin_b_level_before = bcm2835_gpio_lev(this->pin_b);

    //initialize counters
    this->resetCounters();

    cout << "[encoder] initialized!" << endl;
}

void Encoder::process( void ){
    // record current pin levels
    this->pin_a_level = bcm2835_gpio_lev(this->pin_a);
    this->pin_b_level = bcm2835_gpio_lev(this->pin_b);

    pthread_mutex_lock(&(this->lock)); // lock for thread safety
    // check for illegal transition (both pin levels change at the same time)
    if ( (this->pin_a_level != this->pin_a_level_before) && (this->pin_b_level != this->pin_b_level_before) )
        this->illegalCount++;
    else { // no illegal transition ->check which direction is the step and count accordingly
        if (this->pin_a_level != this->pin_a_level_before) { // edge on a
            if (this->pin_a_level) { //positive edge on a
                if (this->pin_b_level) //b high -> lefthand rotation (+)
                    this->rotationCount += this->directionMultiplier;
                else //b low -> righthand rotation (-)
                    this->rotationCount -= this->directionMultiplier;
            } else { //negative edge on a
                if (this->pin_b_level) //b high -> righthand rotation (-)
                    this->rotationCount -= this->directionMultiplier;
                else //b low -> lefthand rotation (+)
                    this->rotationCount += this->directionMultiplier;
            }
        } else if (this->pin_b_level != this->pin_b_level_before) { //edge on b
            if (this->pin_b_level) { //positive edge on b
                if (this->pin_a_level) //a high -> righthand rotation (-)
                    this->rotationCount -= this->directionMultiplier;
                else //a low -> lefthand rotation (+)
                    this->rotationCount += this->directionMultiplier;
            } else { //negative edge on b
                if (this->pin_a_level) //a high -> lefthand rotation (+)
                    this->rotationCount += this->directionMultiplier;
                else //a low -> righthand rotation (-)
                    this->rotationCount -= this->directionMultiplier;
            }
        }
    }
    pthread_mutex_unlock(&(this->lock)); // unlock mutex again


    // save the levels for next execution
    this->pin_a_level_before = this->pin_a_level;
    this->pin_b_level_before = this->pin_b_level;    
}

void Encoder::resetCounters( void ) {
    pthread_mutex_lock(&(this->lock)); // lock for thread safety
    this->rotationCount=0;
    this->illegalCount=0;
    pthread_mutex_unlock(&(this->lock)); // unlock mutex again
    cout << "[encoder] reset counters!" << endl;
}

void Encoder::resetRotation( void ) {
    pthread_mutex_lock(&(this->lock)); // lock for thread safety
    this->rotationCount=0;
    pthread_mutex_unlock(&(this->lock)); // unlock mutex again
    cout << "[encoder] reset rotation count!" << endl;
}
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

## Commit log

2025-04-23 initial commit for the pcb
    [0402CAP_CAP0402CAP.sldprt, 0402RES_RESISTOR0402RES.sldprt, 0805_RESISTOR.sldprt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]
2025-05-12 add encoder on second stepper endstop inputs, add makefile option to install the program as service
2025-05-13 synchronize pin definition in code with pin definition in schematic
2025-05-14 add manual control through enable/left/right buttons
